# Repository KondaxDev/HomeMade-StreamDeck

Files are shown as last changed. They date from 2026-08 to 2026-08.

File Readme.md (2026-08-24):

# Hardware — Bill of Materials

Custom Stream Deck PCB. 4-layer board, 77×46mm, ATmega32U4 + USB-C + I2C OLED + 3×3 button grid.

## Active Components

| Ref | Component | Value / Spec | Footprint | Qty |
|---|---|---|---|---|
| U1 | Microcontroller ATmega32U4 | TQFP-44, native USB | `Package_QFP:TQFP-44_10x10mm_P0.8mm` | 1 |
| U2 | OLED Display, I2C | 0.91", SSD1306 | `Display:ER_OLEDM0.91_1x-I2C` | 1 |
| Y1 | Crystal | 16 MHz | `Crystal:Crystal_SMD_HC49-SD` | 1 |
| J2 | USB-C Connector | Receptacle 14P/16P | `Connector_USB:USB_C_Receptacle...` | 1 |

## Resistors (0805)

| Ref | Role | Value | Footprint | Qty |
|---|---|---|---|---|
| R1 | D- series | 22 Ω | `Resistor_SMD:R_0805_2012Metric` | 1 |
| R2 | D+ series | 22 Ω | `Resistor_SMD:R_0805_2012Metric` | 1 |
| R3 | CC1 | 5.1 kΩ | `Resistor_SMD:R_0805_2012Metric` | 1 |
| R4 | CC2 | 5.1 kΩ | `Resistor_SMD:R_0805_2012Metric` | 1 |
| R5 | D+ pull-up | 1.5 kΩ | `Resistor_SMD:R_0805_2012Metric` | 1 |
| R6 | RESET pull-up | 10 kΩ | `Resistor_SMD:R_0805_2012Metric` | 1 |

## Capacitors (0805)

| Ref | Role | Value | Footprint | Qty |
|---|---|---|---|---|
| C1 | Crystal XTAL1 | 22 pF | `Capacitor_SMD:C_0805_2012Metric` | 1 |
| C2 | Crystal XTAL2 | 22 pF | `Capacitor_SMD:C_0805_2012Metric` | 1 |
| C3 | UCAP | 1 µF | `Capacitor_SMD:C_0805_2012Metric` | 1 |
| C4 | VCC decoupling | 100 nF | `Capacitor_SMD:C_0805_2012Metric` | 1 |
| C5 | UVCC decoupling | 100 nF | `Capacitor_SMD:C_0805_2012Metric` | 1 |
| C6 | AVCC decoupling | 100 nF | `Capacitor_SMD:C_0805_2012Metric` | 1 |

## Buttons

| Ref | Component | Spec | Footprint | Qty |
|---|---|---|---|---|
| SW1–SW9 | Push buttons (3×3 grid) | 6×6mm THT, 4-pin | `Button_Switch_THT:SW_PUSH_6mm` | 9 |
| SW10 | Reset button | 6×6mm THT, 4-pin | `Button_Switch_THT:SW_PUSH_6mm` | 1 |

## Misc

| Item | Spec | Qty |
|---|---|---|
| PCB (4-layer, JLCPCB) | 77×46mm, batch of 5 | 1 batch |
| Button cap | — | 1 (adjust as needed) |

## Unique Part Count

- **1×** ATmega32U4 (U1)
- **1×** SSD1306 OLED display (U2)
- **1×** 16MHz crystal (Y1)
- **1×** USB-C connector (J2)
- **6×** 0805 resistors (R1–R6, various values)
- **6×** 0805 capacitors (C1–C6, various values)
- **10×** 6×6mm THT push buttons (SW1–SW10)
- **1×** PCB (batch of 5, JLCPCB)

**Total parts to solder: 25** (excluding PCB and button cap)

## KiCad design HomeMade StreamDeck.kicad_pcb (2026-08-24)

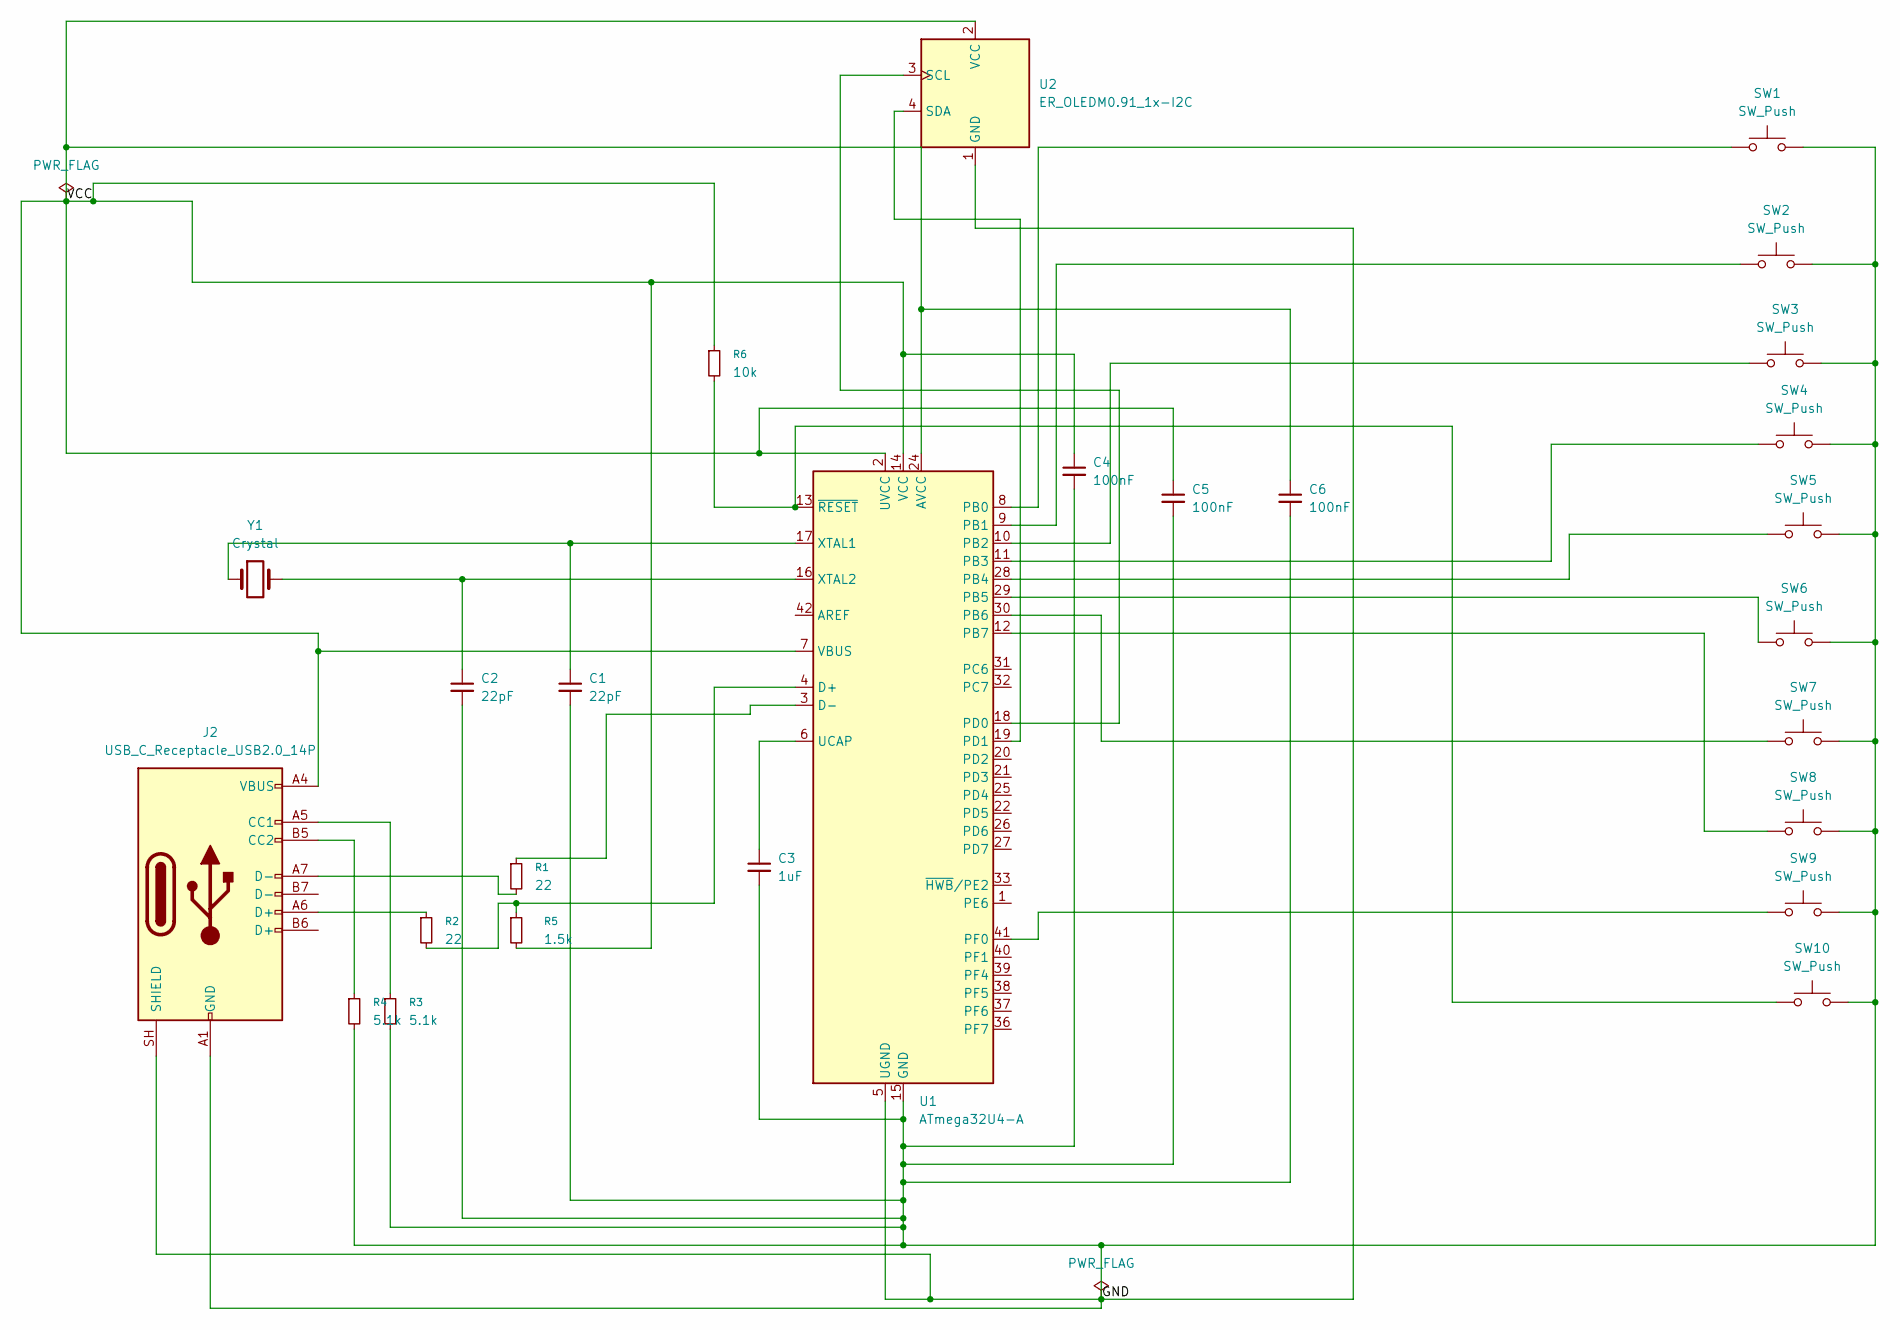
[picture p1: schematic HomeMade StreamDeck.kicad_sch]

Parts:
C1, C2: 22pF; C_0805_2012Metric
C3: 1uF; C_0805_2012Metric
C4, C5, C6: 100nF; C_0805_2012Metric
J2: USB_C_Receptacle_USB2.0_14P; USB_C_Receptacle_HCTL_HC-TYPE-C-16P-01A
R1, R2: 22; R_0805_2012Metric
R3, R4: 5.1k; R_0805_2012Metric
R5: 1.5k; R_0805_2012Metric
R6: 10k; R_0805_2012Metric
SW1, SW2, SW3, SW4, SW5, SW6, SW7, SW8, SW9, SW10: SW_Push; SW_PUSH_6mm
U1: ATmega32U4-A; TQFP-44_10x10mm_P0.8mm
U2: ER_OLEDM0.91_1x-I2C
Y1: Crystal; Crystal_SMD_HC49-SD

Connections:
/GND: C1.2, C2.2, C3.2, C4.2, C5.2, C6.2, J2.A1 (GND), J2.A12 (GND), J2.B1 (GND), J2.B12 (GND), J2.SH (SHIELD), R3.2, R4.2, SW1.2, SW2.2, SW3.2, SW4.2, SW5.2, SW6.2, SW7.2, SW8.2, SW9.2, SW10.2, U1.5 (UGND), U1.15 (GND), U1.23 (GND), U1.35 (GND), U1.43 (GND), U2.1 (GND)
/VCC: C4.1, C5.1, C6.1, J2.A4 (VBUS), J2.A9 (VBUS), J2.B4 (VBUS), J2.B9 (VBUS), R5.2, R6.1, U1.2 (UVCC), U1.7 (VBUS), U1.14 (VCC), U1.24 (AVCC), U1.34 (VCC), U1.44 (AVCC), U2.2 (VCC)
unnamed: J2.A5 (CC1), R3.1
unnamed: J2.B5 (CC2), R4.1
unnamed: J2.A6 (D+), R2.1
unnamed: J2.A7 (D-), R1.2
unnamed: R2.2, R5.1, U1.4 (D+)
unnamed: R1.1, U1.3 (D-)
unnamed: SW1.1, U1.8 (PB0)
unnamed: SW2.1, U1.9 (PB1)
unnamed: SW3.1, U1.10 (PB2)
unnamed: SW4.1, U1.11 (PB3)
unnamed: SW5.1, U1.28 (PB4)
unnamed: SW6.1, U1.29 (PB5)
unnamed: SW7.1, U1.30 (PB6)
unnamed: SW8.1, U1.12 (PB7)
unnamed: U1.18 (PD0), U2.3 (SCL)
unnamed: U1.19 (PD1), U2.4 (SDA)
unnamed: SW9.1, U1.41 (PF0)
unnamed: C3.1, U1.6 (UCAP)
unnamed: C1.1, U1.17 (XTAL1), Y1.1
unnamed: C2.1, U1.16 (XTAL2), Y1.2
unnamed: R6.2, SW10.1, U1.13 (~RESET)

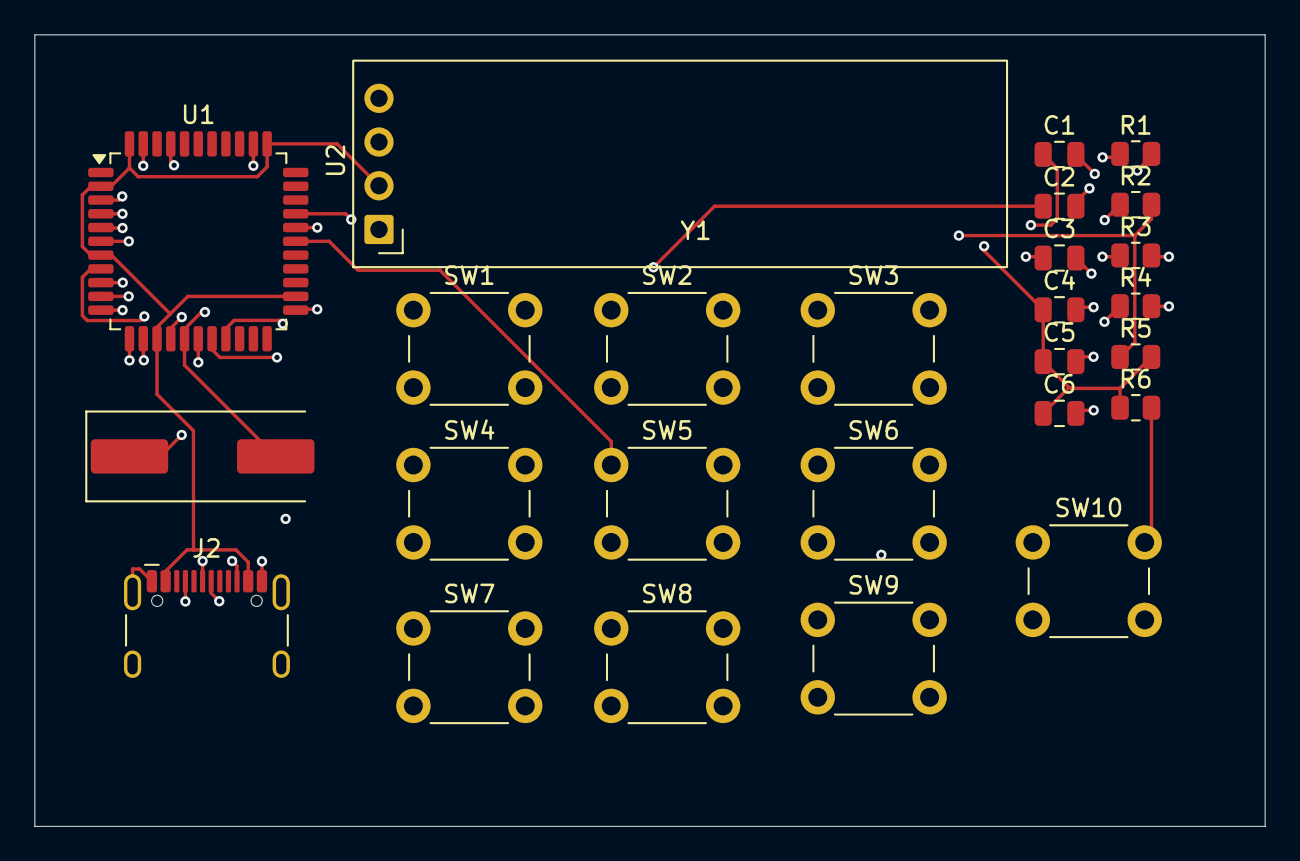
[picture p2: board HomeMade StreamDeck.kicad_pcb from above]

Board: 4 copper layers, 71.5 x 46.0 mm, 26 parts (0 on the bottom side), 23 nets.
